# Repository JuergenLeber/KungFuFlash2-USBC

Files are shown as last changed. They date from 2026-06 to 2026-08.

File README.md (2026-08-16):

# Kung Fu Flash 2 USB-C

Cartridge for the Commodore 64 that packs a punch.

This repository is a fork of [KungFuFlash2-USBC](https://github.com/Sgw32/KungFuFlash2-USBC) which is a fork of an earlier version of [KungFuFlash2](https://codeberg.org/KimJorgensen/KungFuFlash2) from Kim Jørgensen that was later moved to Codeberg and is still being updated.

To have the "best of both worlds" (USB-C and updated firmware) this repository merged both of them together and additionally introduces some small fixes to the PCB and the production files.

Kung Fu Flash 2 is the big brother of [Kung Fu Flash](https://codeberg.org/KimJorgensen/KungFuFlash). It has a faster microcontroller with more memory and I/O pins, allowing for additional functionality.

**Currently, this project is considered experimental** and provides the same features as Kung Fu Flash, with these notable exceptions:

* CRT files are loaded into RAM, not flash, making large CRT files startup faster. However, changes to EasyFlash cartridges are lost if power is turned off, unless saved via the menu first
* The cartridge detects if the C64/C128 is reset. This allows the use of an additional reset button on the C64 or the built-in reset button on the C128
* REU emulation has been added

Kung Fu Flash 2 Launcher

Kung Fu Flash 2 can emulate different cartridge types, load PRG files and use D64 disk images.
Just place your desired CRT, PRG or D64 files on a FAT formatted microSD card and use the built-in launcher to execute them.

## Hardware (Rev. 2)

There are three buttons on the cartridge; a reset button, a menu button for starting the launcher, and a special button that is used by the freezer cartridges.

Cartridge Case

A very nice case has been designed by [Bigby](https://www.printables.com/@Bigby) and can be found on [Printables](https://www.printables.com/model/119330-kung-fu-flash-cartridge-case).

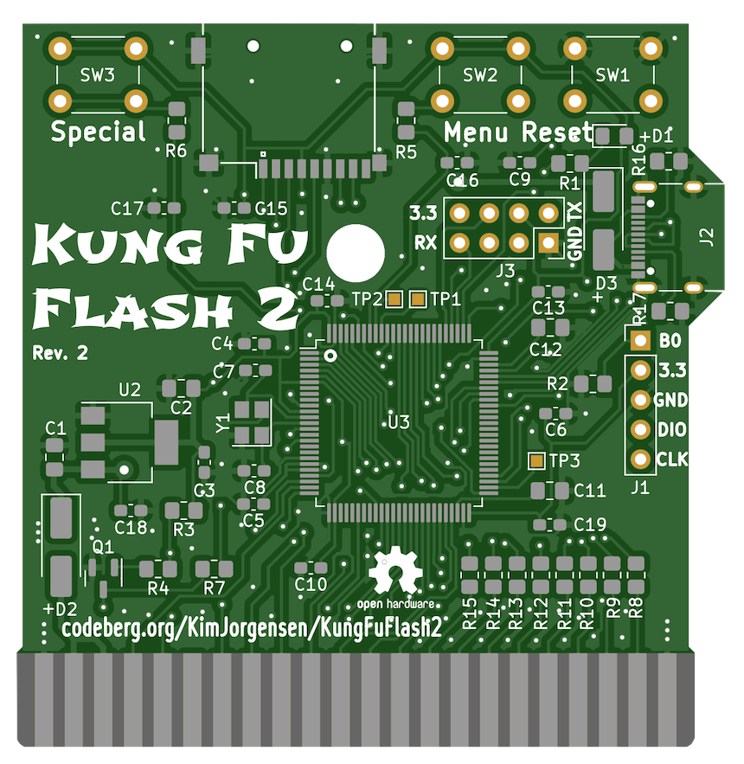
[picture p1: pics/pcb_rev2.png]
Kung Fu Flash 2 PCB


Changes in hardware revision 2 are a USB-C port (including resistors) instead of micro-USB and a different crystal.

As all credits still go to Kim Jørgensen for this great cartridge, the PCB still shows his Codeberg URL.

The gerber files and BOM can be found [here](./hardware/gerber/).

## Supported Cartridges

The following cartridge types are currently supported:

* Generic cartridge (8k, 16k, Ultimax)
* Action Replay v4.x/v5/v6
* KCS Power Cartridge
* Final Cartridge III(+)
* Simons' BASIC
* Fun Play, Power Play
* Super Games
* Ocean type 1
* Epyx Fastload
* C64 Game System, System 3
* WarpSpeed
* Dinamic
* Zaxxon, Super Zaxxon
* Magic Desk, Domark, HES Australia
* Super Snapshot v5
* Comal-80
* Ross
* EasyFlash
* Prophet64
* Freeze Frame
* Freeze Machine
* MACH 5
* Pagefox
* RGCD, Hucky
* Drean
* C128 Generic cartridge (external function ROM)
* WarpSpeed 128

## Supported File Types

The following file types are currently supported:

* Cartridge (CRT)
* C64/C128 generic cartridge (ROM, BIN)
* Disk image (D64, D71, D81)
* Tape image (T64)
* Program (PRG, P00)
* SID tune (SID)
* Firmware update (UPD)
* Text document (TXT, NFO, 1ST)

## SID Playback

SID tunes can be played directly from the launcher. This feature is inherited from the
[KungFuFlash2-USBC](https://github.com/Sgw32/KungFuFlash2-USBC) fork and is not part of the original Kung Fu Flash 2.

Selecting a SID file in the file options menu offers two actions:

* "Play" (RETURN) converts the tune and starts it immediately
* "Convert to PRG" (SHIFT+RETURN) writes a PRG file next to the SID file and returns to the launcher

In both cases the tune is converted to a PRG containing a small BASIC starter and a raster interrupt player,
so the resulting file can also be used on any other C64 setup. As the PRG is written to the microSD card,
the card must not be write protected.

PSID and RSID files of version 1 to 3 are supported, with these limitations:

* Only the first subtune is played; the tune and subtune information from the SID header is ignored
* The player uses a single speed raster interrupt, so multi speed tunes will play at the wrong tempo
* Tunes that load below $0843 cannot be converted, as this area is occupied by the BASIC starter and the player

## REU Emulation

Kung Fu Flash 2 can emulate a 1 Mb REU (RAM Expansion Unit) simultaneously with disk drive emulation.
The REU is enabled in the settings menu (F5) and active when:

* A program is executed using the default option (RETURN)
* A disk image or directory is mounted using "Mount" in the file options menu (SHIFT+RETURN)
* BASIC is started via F6 (C128) or F7 (C64) in the launcher

The REU will not be active when emulating cartridges (CRT files)

## USB Port

The USB port allows programs or disk images to be transferred from/to a PC using the EasyFlash 3 USB protocol.
The USB port is active when:

* The Kung Fu Flash 2 launcher is running
* A program is started using "Load" in the file options menu (SHIFT+RETURN)
* BASIC is started via F7 in the launcher **and** REU emulation is disabled in the settings menu (F5)

Kung Fu Flash 2 shows up as a standard serial port when connected to a PC not requiring any custom drivers to be installed.
This means, however, that the EasyFlash 3 program on the PC side must be modified to support Kung Fu Flash.

The repository of the original Kung Fu Flash contains a modified version of [EasyFlash 3 USB Utilities](https://codeberg.org/KimJorgensen/KungFuFlash/src/branch/master/3rd_party/ef3utils)
and [EasyFlash 3 BBS](https://codeberg.org/KimJorgensen/KungFuFlash/src/branch/master/3rd_party/ef3bbs) which will also work with the Kung Fu Flash 2.

## Firmware Update

Just place the KungFuFlash2_v2.xx.upd file on the SD card and select the file in the launcher to initiate the firmware update.
The newest firmware can be found [here](https://github.com/JuergenLeber/KungFuFlash2-USBC/releases).

For initial firmware installation, [see here](firmware/README.md).

## Limitations

Kung Fu Flash 2 is a so called Software Defined Cartridge where a fast microcontroller emulates cartridge hardware in software.
This makes it extremely flexible, allowing different cartridge types to be supported at a relative low cost.

However, it can be challenging to get the C64 bus timing correct in software and in some places the timing is very close to the limit.
Even though Kung Fu Flash 2 has been tested on different models of the Commodore 64, there is a chance that it doesn't work correctly on your specific model, or requires [phi2 offset adjustment](firmware/README.md#diagnostic).
Use it at your own risk!

Kung Fu Flash 2 will work with the PAL and NTSC version of the Commodore 64 or Commodore 128.

Disk drive emulation is using kernal vectors and will not work with fast loaders or software that uses direct hardware access which a lot of games does.
Currently REL files are not supported and only a subset of the Commodore DOS commands are supported.

## Thanks

Kung Fu Flash 2 was based on or uses other open source projects:

* [Kung Fu Flash](https://codeberg.org/KimJorgensen/KungFuFlash)
* [EasyFlash 3](https://bitbucket.org/skoe/easyflash) by Thomas Giesel
* [Draco Browser](https://csdb.dk/release/?id=89910) by Sascha Bader
* [fatfs-stm32](https://github.com/colosimo/fatfs-stm32) by Aurelio Colosimo
* [FatFs](http://elm-chan.org/fsw/ff/00index_e.html) by ChaN
* [libusb_stm32](https://github.com/dmitrystu/libusb_stm32) by Dmitry Filimonchuk
* [OpenC64Cart](https://github.com/SukkoPera/OpenC64Cart) by Giorgioggì
* [Disk2easyflash](https://csdb.dk/release/?id=150323) by ALeX Kazik

and a few others. Please check the individual files for their license.

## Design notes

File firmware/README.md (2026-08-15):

# Kung Fu Flash 2 Firmware
The initial firmware installation can be done via the SWD interface (J1) using a ST-Link V2 programmer or via the USB port.
The Kung Fu Flash 2 cartridge should not be connected to the Commodore 64 before this process has been completed.

## SWD (Recommended)
Connect the ST-Link V2 programmer to J1 (3.3V, GND, SWDIO, and SWCLK) and connect BOOT0 to 3.3V.

Rename the `KungFuFlash2_v2.xx.upd` file to `KungFuFlash2_v2.xx.bin` and use the STM32CubeProgrammer from ST to program the firmware.

All wires to J1 should be disconnected once the firmware has been successfully installed.

## USB
Add a jumper to short BOOT0 and +3.3V on J1. This will ensure that the board is started in DFU mode.

Use [dfu-util](http://dfu-util.sourceforge.net/) to install the firmware:

`dfu-util -a 0 -s 0x08000000 -D KungFuFlash2_v2.xx.upd`

The jumper should be removed after the firmware has been installed.

## Diagnostic
The diagnostic tool is started by pressing the menu button for 2 seconds (until the LED turns off) and is intended to debug stability problems on some C64 models.
For reference the phi2 clock frequency should be around 985248 Hz for PAL and around 1022727 Hz for NTSC.

The diagnostic tool allows adjusting a phi2 clock offset to address any stability issues.
Some C64 breadbin/longboards may require a small negative phi2 offset and C64C/shortboards may require a small positive offset.

In the diagnostic tool the following buttons on the cartridge can be used:

* `Special`: Decrease offset
* `Menu`: Increase offset
* `Special`, hold for 2 seconds: Save offset and exit
* `Menu`, hold for 2 seconds: Reset offset (without saving)
* `Special` + `Menu`, hold for 2 seconds: Reset and save offset. This combo will also work without starting the diagnostic tool first
* `Reset`: Exit diagnostic tool without saving offset

The phi2 offset is saved to the hidden `.KFF2.cfg` file and is reset if the file is not found on the SD card.

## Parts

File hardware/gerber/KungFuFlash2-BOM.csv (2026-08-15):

# | Reference | Qty | Manf | Manf# | LCSC Part# | Description | Value | Footprint | DNP
1 | C1,C2 | 2 | Samsung Electro-Mechanics | CL21A106KAYNNNG | C318691 |  | 10u | Capacitor_SMD:C_0805_2012Metric_Pad1.18x1.45mm_HandSolder
2 | C3,C4,C5,C6,C9,C10,C13,C14,C15,C16,C17,C18,C19 | 13 | Samsung Electro-Mechanics | CL10B104KB8NNNC | C1591 |  | 100n | Capacitor_SMD:C_0603_1608Metric_Pad1.08x0.95mm_HandSolder
3 | C7,C8 | 2 | Samsung Electro-Mechanics | CL10C200JB81PNC | C346210 |  | 20p | Capacitor_SMD:C_0603_1608Metric_Pad1.08x0.95mm_HandSolder
4 | C11,C12 | 2 | Samsung Electro-Mechanics | CL21B225KBYVPNE | C5362585 |  | 2.2u | Capacitor_SMD:C_0805_2012Metric_Pad1.18x1.45mm_HandSolder
5 | D1 | 1 | Hubei KENTO Elec | KT-0805G | C2297 | LED | Green | LED_SMD:LED_0805_2012Metric_Pad1.15x1.40mm_HandSolder
6 | D2,D3 | 2 | MDD | SS33 | C64998 |  | D_Schottky | Diode_SMD:D_SMA_Handsoldering
7 | J1 | 1 | DNP | DNP | DNP | SWD | DNP | Connector_PinHeader_2.54mm:PinHeader_1x05_P2.54mm_Vertical | DNP
8 | J2 | 1 | Korean Hroparts Elec | TYPE-C-31-M-12 | C165948 | USB-C | USB_C_Receptacle_USB2.0 | Connector_USB:USB_C_Receptacle_XKB_U262-16XN-4BVC11
9 | J3 | 1 | DNP | DNP | DNP | WiFi-Module | DNP | Connector_PinSocket_2.54mm:PinSocket_2x04_P2.54mm_Vertical | DNP
10 | Q1 | 1 | JSMSEMI | BC817 | C916383 |  | BC817-40 | Package_TO_SOT_SMD:SOT-23
11 | R1,R4,R5,R6,R7 | 5 | FH | RS-05K5100FT | C139861 |  | 510R | Resistor_SMD:R_0805_2012Metric_Pad1.20x1.40mm_HandSolder
12 | R2,R3 | 2 | FH | RS-05K1002FT | C115309 |  | 10k | Resistor_SMD:R_0805_2012Metric_Pad1.20x1.40mm_HandSolder
13 | R8,R9,R10,R11,R12,R13,R14,R15 | 8 | FH | RS-05K1000FT | C115424 |  | 100R | Resistor_SMD:R_0805_2012Metric_Pad1.20x1.40mm_HandSolder
14 | R16,R17 | 2 | FH | RS-05K5101FT | C118848 |  | 5.1k | Resistor_SMD:R_0805_2012Metric_Pad1.20x1.40mm_HandSolder
15 | SW1,SW2,SW3 | 3 | SHOU HAN | SH-6X6X5H-CJ | C42416245 | Reset, Menu, Special | Tactile Switch SPST 250gf 5mm PC Pin 6mm x 6mm Through Hole | Button_Switch_THT:SW_PUSH_6mm_H8mm
16 | U2 | 1 | Advanced Monolithic Systems | AMS1117-3.3 | C6186 |  | AMS1117-3.3 | Package_TO_SOT_SMD:SOT-223-3_TabPin2
17 | U3 | 1 | ST | STM32H7B0VBT6 | C730227 |  | STM32H7B0VBTx | Package_QFP:LQFP-100_14x14mm_P0.5mm
18 | XS1 | 1 | SOFNG | TF-15x15 | C111196 |  | uSD_push_push | KungFuFlash2:Conn_uSDcard
19 | Y1 | 1 | YXC Crystal Oscillators | X322525MOB4SI | C9006 |  | 25 MHz | Crystal:Crystal_SMD_3225-4Pin_3.2x2.5mm

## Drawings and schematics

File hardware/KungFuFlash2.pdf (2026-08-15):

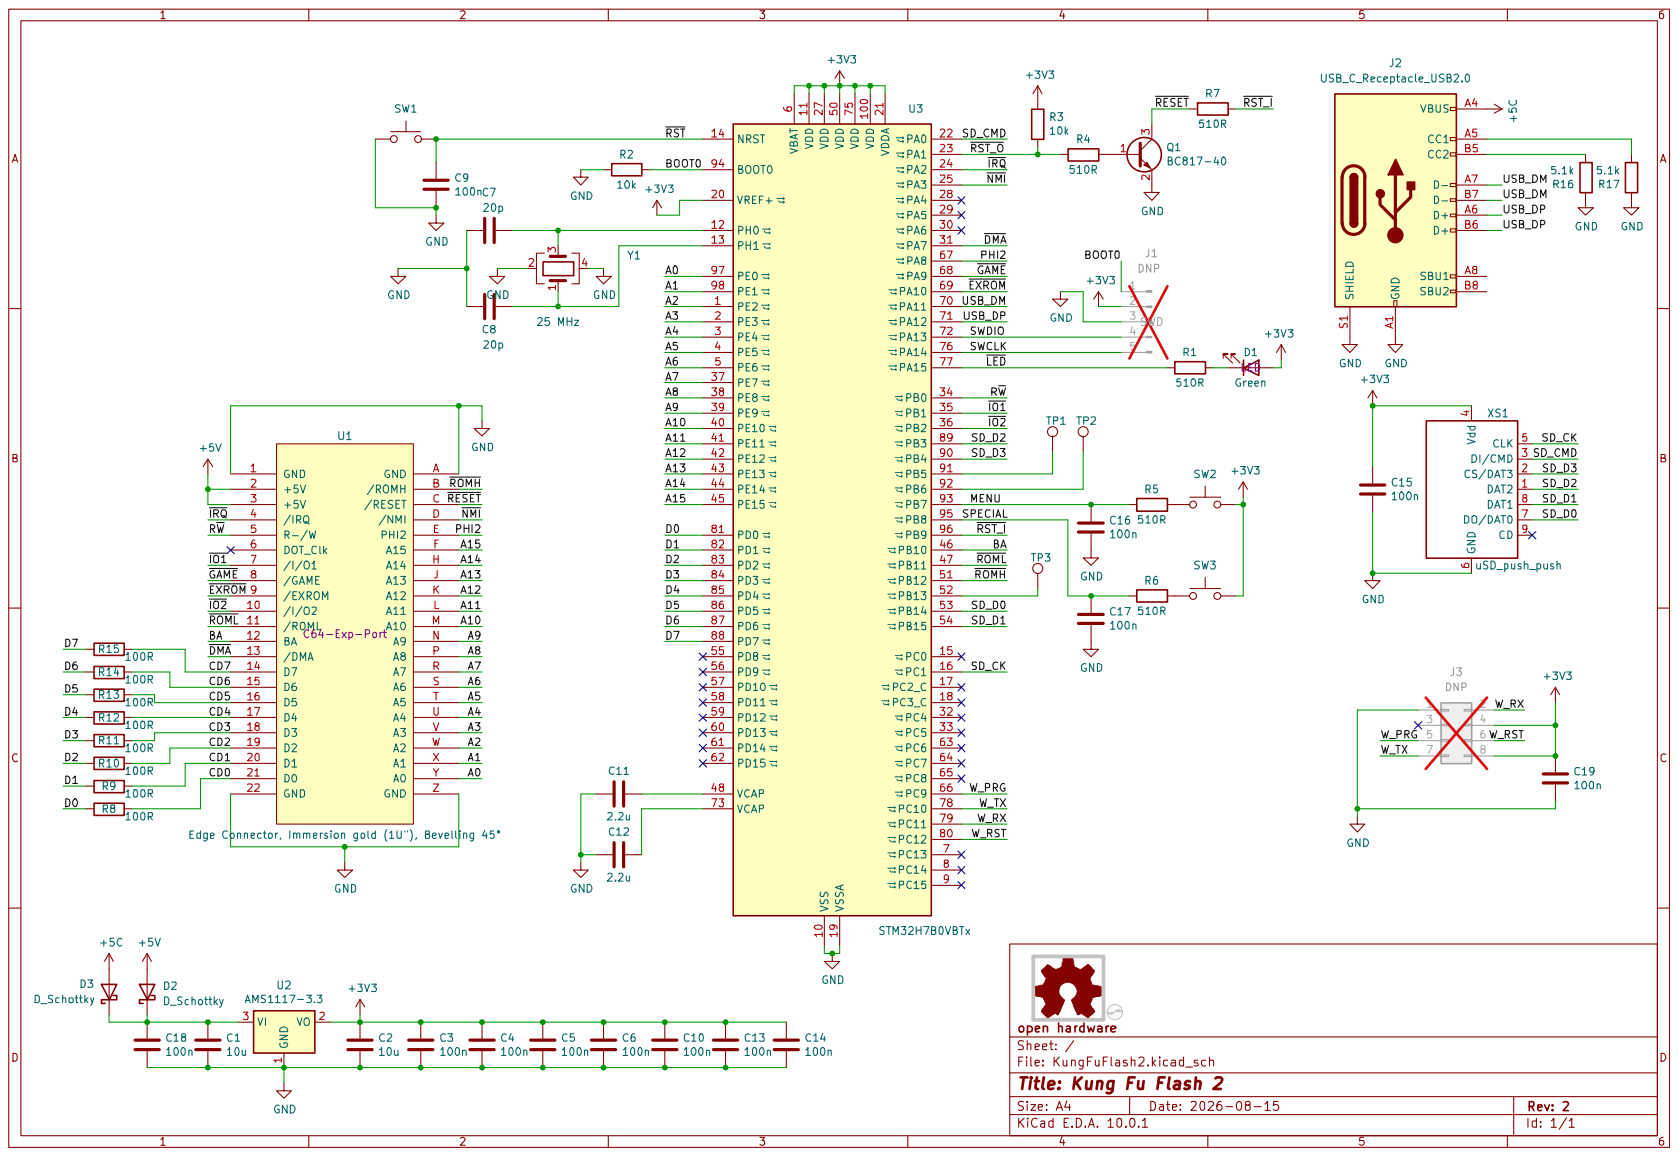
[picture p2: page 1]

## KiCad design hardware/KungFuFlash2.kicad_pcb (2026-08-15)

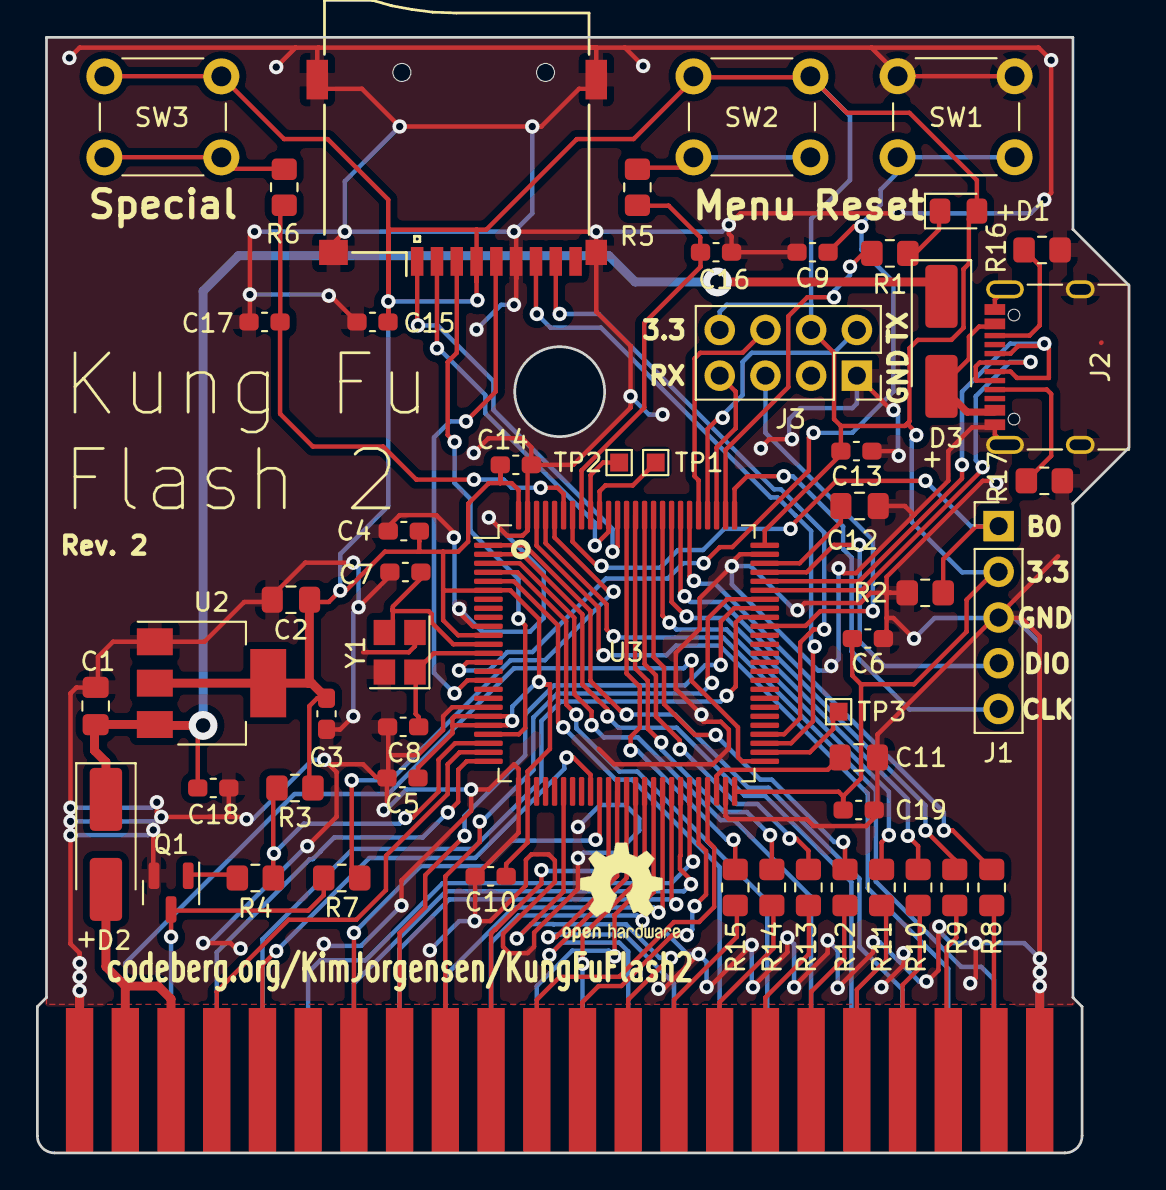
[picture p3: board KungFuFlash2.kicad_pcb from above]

Board: 2 copper layers, 60.6 x 62.0 mm, 54 parts (0 on the bottom side), 84 nets.

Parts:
C1, C2: 10u; C_0805_2012Metric_Pad1.18x1.45mm_HandSolder
C3, C4, C5, C6, C9, C10, C13, C14, C15, C16, C17, C18, C19: 100n; C_0603_1608Metric_Pad1.08x0.95mm_HandSolder
C7, C8: 20p; C_0603_1608Metric_Pad1.08x0.95mm_HandSolder
C11, C12: 2.2u; C_0805_2012Metric_Pad1.18x1.45mm_HandSolder
D1: LED; LED_0805_2012Metric_Pad1.15x1.40mm_HandSolder
D2, D3: D_Schottky; D_SMA_Handsoldering
J1: SWD; PinHeader_1x05_P2.54mm_Vertical
J2: USB_C_Receptacle_USB2.0; USB_C_Receptacle_XKB_U262-16XN-4BVC11
J3: Wifi; PinSocket_2x04_P2.54mm_Vertical
Q1: BC817; SOT-23
R1, R4, R5, R6, R7: 510R; R_0805_2012Metric_Pad1.20x1.40mm_HandSolder
R2, R3: 10k; R_0805_2012Metric_Pad1.20x1.40mm_HandSolder
R8, R9, R10, R11, R12, R13, R14, R15: 100R; R_0805_2012Metric_Pad1.20x1.40mm_HandSolder
R16, R17: 5.1k; R_0805_2012Metric_Pad1.20x1.40mm_HandSolder
SW1: Reset; SW_PUSH_6mm_H8mm
SW2: Menu; SW_PUSH_6mm_H8mm
SW3: Special; SW_PUSH_6mm_H8mm
TP1, TP2, TP3: TestPoint_Pad_1.0x1.0mm
U1: C64-Exp-Port; C64-Cart
U2: AMS1117-3.3; SOT-223-3_TabPin2
U3: STM32H7B0VBTx; LQFP-100_14x14mm_P0.5mm
XS1: uSD_push_push; Conn_uSDcard
Y1: 25 MHz; Crystal_SMD_3225-4Pin_3.2x2.5mm

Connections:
+3V3: C2.1, C3.1, C4.1, C5.1, C6.1, C10.1, C13.1, C14.1, C15.1, C19.1, D1.2 (A), J1.2, J3.4, J3.8, R3.1, SW2.1, SW3.1, U2.2 (VO), U3.6 (VBAT), U3.11 (VDD), U3.20 (VREF+), U3.21 (VDDA), U3.27 (VDD), U3.50 (VDD), U3.75 (VDD), U3.100 (VDD), XS1.4 (Vdd)
+5C: D3.2 (A), J2.A4 (VBUS), J2.A9 (VBUS), J2.B4 (VBUS), J2.B9 (VBUS)
+5V: D2.2 (A), U1.2 (+5V), U1.3 (+5V)
/A0: U1.Y (A0), U3.97 (PE0)
/A1: U1.X (A1), U3.98 (PE1)
/A2: U1.W (A2), U3.1 (PE2)
/A3: U1.V (A3), U3.2 (PE3)
/A4: U1.U (A4), U3.3 (PE4)
/A5: U1.T (A5), U3.4 (PE5)
/A6: U1.S (A6), U3.5 (PE6)
/A7: U1.R (A7), U3.37 (PE7)
/A8: U1.P (A8), U3.38 (PE8)
/A9: U1.N (A9), U3.39 (PE9)
/A10: U1.M (A10), U3.40 (PE10)
/A11: U1.L (A11), U3.41 (PE11)
/A12: U1.K (A12), U3.42 (PE12)
/A13: U1.J (A13), U3.43 (PE13)
/A14: U1.H (A14), U3.44 (PE14)
/A15: U1.F (A15), U3.45 (PE15)
/BA: U1.12 (BA), U3.46 (PB10)
/BOOT0: J1.1, R2.1, U3.94 (BOOT0)
/CD0: R8.1, U1.21 (D0)
/CD1: R9.1, U1.20 (D1)
/CD2: R10.1, U1.19 (D2)
/CD3: R11.1, U1.18 (D3)
/CD4: R12.1, U1.17 (D4)
/CD5: R13.1, U1.16 (D5)
/CD6: R14.1, U1.15 (D6)
/CD7: R15.1, U1.14 (D7)
/D0: R8.2, U3.81 (PD0)
/D1: R9.2, U3.82 (PD1)
/D2: R10.2, U3.83 (PD2)
/D3: R11.2, U3.84 (PD3)
/D4: R12.2, U3.85 (PD4)
/D5: R13.2, U3.86 (PD5)
/D6: R14.2, U3.87 (PD6)
/D7: R15.2, U3.88 (PD7)
/MENU: C16.1, R5.2, U3.93 (PB7)
/PHI2: U1.E (PHI2), U3.67 (PA8)
/R~W: U1.5 (R-/W), U3.34 (PB0)
/SD_CK: U3.16 (PC1), XS1.5 (CLK)
/SD_CMD: U3.22 (PA0), XS1.3 (DI/CMD)
/SD_D0: U3.53 (PB14), XS1.7 (DO/DAT0)
/SD_D1: U3.54 (PB15), XS1.8 (DAT1)
/SD_D2: U3.89 (PB3), XS1.1 (DAT2)
/SD_D3: U3.90 (PB4), XS1.2 (CS/DAT3)
/SPECIAL: C17.1, R6.2, U3.95 (PB8)
/SWCLK: J1.5, U3.76 (PA14)
/SWDIO: J1.4, U3.72 (PA13)
/USB_DM: J2.A7 (D-), J2.B7 (D-), U3.70 (PA11)
/USB_DP: J2.A6 (D+), J2.B6 (D+), U3.71 (PA12)
/W_PRG: J3.5, U3.66 (PC9)
/W_RST: J3.6, U3.80 (PC12)
/W_RX: J3.2, U3.79 (PC11)
/W_TX: J3.7, U3.78 (PC10)
/~DMA: U1.13 (/DMA), U3.31 (PA7)
/~EXROM: U1.9 (/EXROM), U3.69 (PA10)
/~GAME: U1.8 (/GAME), U3.68 (PA9)
/~IO1: U1.7 (/I/O1), U3.35 (PB1)
/~IO2: U1.10 (/I/O2), U3.36 (PB2)
/~IRQ: U1.4 (/IRQ), U3.24 (PA2)
/~LED: R1.1, U3.77 (PA15)
/~NMI: U1.D (/NMI), U3.25 (PA3)
/~RESET: Q1.3 (C), R7.2, U1.C (/RESET)
/~ROMH: U1.B (/ROMH), U3.51 (PB12)
/~ROML: U1.11 (/ROML), U3.47 (PB11)
/~RST_I: R7.1, U3.96 (PB9)
/~RST_O: R3.2, R4.2, U3.23 (PA1)
/~RST: C9.1, SW1.2, U3.14 (NRST)
GND: C1.2, C2.2, C3.2, C4.2, C5.2, C6.2, C7.1, C8.1, C9.2, C10.2, C11.1, C12.2, C13.2, C14.2, C15.2, C16.2, C17.2, C18.2, C19.2, J1.3, J2.A1 (GND), J2.A12 (GND), J2.B1 (GND), J2.B12 (GND), J2.S1 (SHIELD), J3.1, Q1.2 (E), R2.2, R16.1, R17.1, SW1.1, U1.1 (GND), U1.22 (GND), U1.A (GND), U1.Z (GND), U2.1 (GND), U3.10 (VSS), U3.19 (VSSA), U3.26 (VSS), U3.49 (VSS), U3.74 (VSS), U3.99 (VSS), XS1.6 (GND), Y1.2, Y1.4
unnamed: C11.2, U3.48 (VCAP)
unnamed: C12.1, U3.73 (VCAP)
unnamed: D1.1 (K), R1.2
unnamed: C1.1, C18.1, D2.1 (K), D3.1 (K), U2.3 (VI)
unnamed: J2.A5 (CC1), R17.2
unnamed: J2.B5 (CC2), R16.2
unnamed: Q1.1 (B), R4.1
unnamed: R5.1, SW2.2
unnamed: R6.1, SW3.2
unnamed: TP1.1, U3.91 (PB5)
unnamed: TP2.1, U3.92 (PB6)
unnamed: TP3.1, U3.52 (PB13)
unnamed: C7.2, U3.12 (PH0), Y1.3
unnamed: C8.2, U3.13 (PH1), Y1.1

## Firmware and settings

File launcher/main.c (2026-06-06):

/*
 * Copyright (c) 2019-2026 Kim Jørgensen
 *
 * This software is provided 'as-is', without any express or implied
 * warranty.  In no event will the authors be held liable for any damages
 * arising from the use of this software.
 *
 * Permission is granted to anyone to use this software for any purpose,
 * including commercial applications, and to alter it and redistribute it
 * freely, subject to the following restrictions:
 *
 * 1. The origin of this software must not be misrepresented; you must not
 *    claim that you wrote the original software. If you use this software
 *    in a product, an acknowledgment in the product documentation would be
 *    appreciated but is not required.
 * 2. Altered source versions must be plainly marked as such, and must not be
 *    misrepresented as being the original software.
 * 3. This notice may not be removed or altered from any source distribution.
 *
 ******************************************************************************
 * Derived from Draco Browser V1.0C 8 Bit (27.12.2009)
 * Created 2009 by Sascha Bader
 *
 * The code can be used freely as long as you retain
 * a notice describing original source and author.
 *
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
 * Newer versions might be available here: http://www.sascha-bader.de/html/code.html
 */

#include <stdio.h>
#include <string.h>
#include <stdlib.h>
#include <stdbool.h>
#include <ctype.h>
#include <conio.h>
#include <cbm.h>
#include <errno.h>
#include <joystick.h>
#include "screen.h"
#include "dir.h"
#include "base.h"
#include "kff_data.h"
#include "ef3usb_loader.h"
#include "disk.h"
#include "launcher_asm.h"

/* declarations */
static void mainLoopEF3(void);
static void mainLoopKFF(void);
static void textReaderLoop(void);
static uint8_t menuLoop(void);

static void updateScreen(void);
static void help(void);
static bool isSearchChar(uint8_t c);
static uint8_t search(uint8_t c);
static void showDir(void);
static void updateDir(uint8_t last_selected);
static void printDirPage(void);
static void printElement(uint8_t pos);

static const char *kff_receive_text(uint16_t size);
static const char *kff_read_text(void);
static uint8_t kff_sync(void);
static void showFrame(const char *title);
static void showKFFMessage(uint8_t color);
static void showKFFCancel(void);
static void showMessage(const char *text, uint8_t color);

/* definitions */
#define EF3_USB_CMD_LEN 12

static bool isC128 = false;

static char linebuffer[SCREENW+1];
static char inputBuffer[SEARCH_LENGTH+1];
static char searchBuffer[SEARCH_LENGTH+1];
static uint8_t searchLen = 0;
static uint8_t *bigBuffer = NULL;
static uint16_t *pageBuffer = NULL;
static Directory *dir = NULL;

#define KUNG_FU_FLASH_VER "Kung Fu Flash v" ## KFF_VER

// Place program name in the start of the output file
// so it can be read by the firmware
#pragma rodata-name (push, "LOWCODE")
const char programNameVer[FW_NAME_SIZE] = KUNG_FU_FLASH_VER;
#pragma rodata-name (pop)

static const char programBar[] = {"          " KUNG_FU_FLASH_VER "           "};
static const char menuBar[] =    {"          " KUNG_FU_FLASH_VER "  <F1> Help"};

int main(void)
{
    uint8_t i, tmp, tst;
    initScreen(COLOR_BLACK, COLOR_BLACK, TEXTC);

    dir = (Directory *)malloc(sizeof(Directory));
    bigBuffer = (uint8_t *)dir;
    pageBuffer = (uint16_t *)dir;

    if (dir == NULL)
    {
        showMessage("Failed to allocate memory.", ERRORC);
        while (true);
    }

    if (joy_install(&joy_static_stddrv) != JOY_ERR_OK)
    {
        showMessage("Failed to install joystick driver.", ERRORC);
        while (true);
    }

    isC128 = is_c128() != 0;

    if (USB_STATUS == KFF_ID_VALUE) // KFF mode
    {
        mainLoopKFF();
    }
    else    // EF3 mode
    {
        // We can also end up here if there is a hardware problem
        // Test EF3 RAM to make sure we are indeed in EF3 mode
        tst = tmp = EF_RAM_TEST;
        for (i=0; i<=8; i++)
        {
            if (EF_RAM_TEST != tst)
            {
                showMessage("Communication with cartridge failed.", ERRORC);
                cprintf("Check hardware");
                while (true);
            }
            EF_RAM_TEST = tst = 1<<i;
        }
        EF_RAM_TEST = tmp;

        mainLoopEF3();
    }

    free(dir);
    return 0;
}

static void mainLoopEF3(void)
{
    uint8_t i;
    const char *cmd;

    // Get command from Kung Fu Flash cartridge using the EF3 USB protocol
    for (i=0; i<EF3_USB_CMD_LEN; i++)
    {
        cmd = ef3usb_check_cmd();
    }

    while (true)
    {
        if (cmd == NULL)
        {
            showMessage("Communicating with USB...", WARNC);
        }
        else if (strcmp(cmd, "prg") == 0)   // Load PRG
        {
            ef3usb_send_str("load");
            ef3usb_load_and_run();
        }
        else
        {
            showMessage("Received unsupported command.", ERRORC);
            cprintf("Command: %s", cmd);
            ef3usb_send_str("etyp");
        }

        while (!(cmd = ef3usb_check_cmd()));
    }
}

static void mainLoopKFF(void)
{
    const char *text;
    uint8_t cmd, reply, cxy[3];
    uint16_t cmd_wait = 0;

    // Get command from Kung Fu Flash cartridge using the KFF protocol
    while (!(cmd = KFF_GET_COMMAND()) || cmd >= REPLY_OK)
    {
        if (++cmd_wait > 10000)
        {
            cmd_wait = 0;
            showMessage("Waiting for command from cartridge.", ERRORC);
            cprintf("Command: %x", cmd);
        }
    }

    while (true)
    {
        reply = REPLY_OK;
        switch (cmd)
        {
            case CMD_NONE:
                break;

            case CMD_MESSAGE:
                showKFFMessage(TEXTC);
                break;

            case CMD_WARNING:
                showKFFMessage(WARNC);
                waitKey();
                reply = kff_sync();
                break;

            case CMD_FLASH_MESSAGE:
                showKFFMessage(TEXTC);
                textcolor(ERRORC);
                cprintf("PLEASE DO NOT POWER OFF OR RESET");
                reply = kff_sync();
                break;

            case CMD_CANCEL_MESSAGE:
                showKFFCancel();
                reply = kff_sync();
                break;

            case CMD_TEXT:
            case CMD_TEXT_WAIT:
                kff_receive_data(&cxy, sizeof(cxy));
                text = kff_read_text();
                textcolor(cxy[0]);
                cputsxy(cxy[1], cxy[2], text);
                if (cmd == CMD_TEXT_WAIT)
                {
                    reply = kff_sync();
                }
                break;

            case CMD_TEXT_READER:
                textReaderLoop();
                wait_for_reset();
                break;

            case CMD_MENU:
                cmd = menuLoop();
                continue;

            case CMD_WAIT_SYNC:
                clrscr();
                reply = kff_sync();
                break;

            case CMD_MOUNT_DISK:
                disk_mount_and_load();
                break;

            case CMD_WAIT_RESET:
                wait_for_reset();
                break;

            default:
                showMessage("Communication with cartridge failed.", ERRORC);
                cprintf("Unexpected command: %x", cmd);
                break;
        }

        cmd = kff_send_reply(reply);
    }
}

static const char *kff_receive_text(uint16_t size)
{
    kff_receive_data(bigBuffer, size);
    bigBuffer[size] = 0;

    return bigBuffer;
}

static const char *kff_read_text(void)
{
    uint16_t size;
    kff_receive_data(&size, 2);

    return kff_receive_text(size);
}

static void showKFFMessage(uint8_t color)
{
    const char *text = kff_read_text();
    showMessage(text, color);
}

static void showKFFCancel(void)
{
    const char *text = kff_receive_text(DIR_NAME_LENGTH);
    sprintf(linebuffer, "%-39s ", text);
    showFrame(linebuffer);

    textcolor(TEXTC);
    text = kff_read_text();
    cputsxy(0, 3, text);

    textcolor(ERRORC);
    cputsxy(0, 5, "PLEASE DO NOT POWER OFF OR RESET");

    revers(1);
    textcolor(COLOR_PURPLE);
    cputsxy(0, 11, "PRESS A KEY TO CANCEL");
    revers(0);
}

static uint8_t kff_sync(void)
{
    kff_wait_for_sync();

    if (kbhit() || joyhit())
    {
        return REPLY_CANCEL;
    }

    return REPLY_OK;
}

static void showTextPage(uint16_t page)
{
    uint8_t i, chr, last_c = 0;

    clrscr();
    revers(1);
    textcolor(BACKC);
    gotoxy(0, 0);
    KFF_READ_PTR = 0;
    for (i=0; i<DIR_NAME_LENGTH; i++)
    {
        cputc(KFF_DATA);
    }
    cputc(' ');
    cputsxy(0, BOTTOM, programBar);
    revers(0);
    textcolor(TEXTC);
    gotoxy(0, 1);

    KFF_READ_PTR = pageBuffer[page];
    while (true)
    {
        chr = KFF_DATA;
        if (!chr || wherey() >= 24)
        {
            (KFF_READ_PTR)--;
            break;
        }

        if (chr == 0x0a && last_c != 0x0d)  // Handle line endings
        {
            cputs("\r\n");
        }
        else if (chr == 0x09)   // Handle tab
        {
            if ((wherex() % 2) == 0)
            {
                cputs("  ");
            }
            else
            {
                cputc(' ');
            }
        }
        else
        {
            cputc(chr);
        }

        last_c = chr;
    }

    pageBuffer[page + 1] = KFF_READ_PTR;
}

static void textReaderLoop(void)
{
    uint8_t c;
    uint16_t size, page = 0;

    KFF_READ_PTR = DIR_NAME_LENGTH;
    kff_receive_data(&size, 2);
    size++;
    pageBuffer[0] = KFF_READ_PTR;
    showTextPage(0);

    waitRelease();
    while (true)
    {
        c = kbhit() ? cgetc() : getJoy();
        switch (c)
        {
            case CH_ENTER:
            case CH_SHIFT_ENTER:
            case CH_DEL:
            case CH_STOP:
                return;

            case CH_HOME:
            case CH_FIRE_LEFT:
            case CH_FIRE_UP:
                page = 0;
                showTextPage(page);
                break;

            case CH_CURS_DOWN:
            case CH_CURS_RIGHT:
                if (KFF_READ_PTR < size && page < (sizeof(Directory)/2))
                {
                    showTextPage(++page);
                }
                break;

            case CH_CURS_LEFT:
            case CH_CURS_UP:
                if (page)
                {
                    showTextPage(--page);
                }
                break;

            default:
                break;
        }
    }
}

static void updateScreen(void)
{
    clrscr();
    revers(0);
    textcolor(BACKC);
    drawFrame();
    revers(1);
    cputsxy(0, BOTTOM, menuBar);
    revers(0);

    showDir();
}

static uint8_t menuLoop(void)
{
    uint8_t c, last_selected = 0;
    uint8_t data, cmd, reply;

    memset(dir, 0, sizeof(Directory));
    updateScreen();

    cmd = CMD_NONE;
    kff_send_size_data(searchBuffer, searchLen);
    reply = REPLY_DIR;

    while (true)
    {
        if (cmd != CMD_NONE || reply != REPLY_OK)
        {
            cmd = kff_send_reply_progress(reply);
        }

        reply = REPLY_OK;
        switch (cmd)
        {
            case CMD_NONE:
                break;

            case CMD_READ_DIR:
                readDir(dir);
                showDir();
                waitRelease();
                continue;

            case CMD_READ_DIR_PAGE:
                if (!readDirPage(dir))
                {
                    dir->selected = last_selected;
                }

                if (dir->selected >= dir->no_of_elements)
                {
                    dir->selected =
                        dir->no_of_elements ? dir->no_of_elements-1 : 0;
                }

                if (dir->selected < dir->text_elements)
                {
                    dir->selected = dir->text_elements;
                }

                showDir();
                continue;

            default:
                return cmd;
        }

        c = kbhit() ? cgetc() : getJoy();
        switch (c)
        {
            case CH_NONE:
                break;

            // --- start / enter directory
            case CH_ENTER:
            case CH_SHIFT_ENTER:
                if (dir->no_of_elements)
                {
                    data = dir->selected;
                    if (isC128)
                    {
                        data |= SELECT_FLAG_C128;
                    }
                    if (c == CH_SHIFT_ENTER)
                    {
                        data |= SELECT_FLAG_OPTIONS;
                    }

                    KFF_SEND_BYTE(data);
                    reply = REPLY_SELECT;
                }
                break;

            // --- leave directory
            case CH_DEL:
            case CH_FIRE_LEFT:
                if (searchBuffer[0] && *dir->name != ' ')
                {
                    reply = search(c);
                }
                else
                {
                    reply = REPLY_DIR_UP;
                }
                break;

            // --- root directory
            case CH_HOME:
                if (searchBuffer[0] && *dir->name != ' ')
                {
                    reply = search(c);
                }
                else
                {
                    reply = REPLY_DIR_ROOT;
                }
                break;

            case CH_CURS_DOWN:
                if (dir->no_of_elements)
                {
                    last_selected = dir->selected;
                    if ((dir->selected+1) < dir->no_of_elements)
                    {
                        dir->selected++;
                        updateDir(last_selected);
                    }
                    else if (dir->no_of_elements == MAX_ELEMENTS_PAGE)
                    {
                        dir->selected = 0;
                        reply = REPLY_DIR_NEXT_PAGE;
                    }
                }
                break;

            case CH_CURS_UP:
                if (dir->no_of_elements)
                {
                    last_selected = dir->selected;
                    if (dir->selected > dir->text_elements)
                    {
                        dir->selected--;
                        updateDir(last_selected);
                    }
                    else
                    {
                        dir->selected = MAX_ELEMENTS_PAGE-1;
                        reply = REPLY_DIR_PREV_PAGE;
                    }
                }
                break;

            case CH_CURS_RIGHT:
                if (dir->no_of_elements)
                {
                    if (dir->no_of_elements < MAX_ELEMENTS_PAGE)
                    {
                        last_selected = dir->selected;
                        dir->selected = dir->no_of_elements-1;
                        updateDir(last_selected);
                    }
                    else
                    {
                        last_selected = dir->no_of_elements-1;
                        reply = REPLY_DIR_NEXT_PAGE;
                    }
                }
                break;

            case CH_CURS_LEFT:
                if (dir->no_of_elements)
                {
                    last_selected = 0;
                    reply = REPLY_DIR_PREV_PAGE;
                }
                break;

            // --- search
            case CH_INS:
            case CH_FIRE_UP:
                if (*dir->name != ' ')
                {
                    reply = search(c);
                }
                break;

            // --- clear search
            case CH_CLR:
                if (searchBuffer[0] && *dir->name != ' ')
                {
                    reply = search(c);
                }
                break;

            case CH_F1:
                help();
                break;

            case CH_F3:
                reply = REPLY_UTILITIES;
                break;

            case CH_FIRE_DOWN:
                if (searchBuffer[0] && *dir->name != ' ')
                {
                    reply = search(c);
                }
                else
                {
                    reply = REPLY_UTILITIES;
                }
                break;

            case CH_F5:
                reply = REPLY_SETTINGS;
                break;

            case CH_FIRE_RIGHT:
                if (searchBuffer[0] && *dir->name != ' ')
                {
                    reply = search(c);
                }
                else
                {
                    reply = REPLY_SETTINGS;
                }
                break;

            case CH_F6:
                reply = REPLY_BASIC_C128;
                break;

            case CH_F7:
                reply = REPLY_BASIC;
                break;

            case CH_F8:
                reply = REPLY_KILL;
                break;

            case CH_STOP:
                reply = REPLY_RESET;
                break;

            default:
                if (isSearchChar(c) && *dir->name != ' ')
                {
                    reply = search(c);
                }
                break;
        }
    }
}

static bool isSearchChar(uint8_t c)
{
    return (c >= 0x20 && c <= 0x5f) || (c >= 0xc1 && c <= 0xda);
}

static uint8_t search(uint8_t c)
{
    uint8_t cursor_pos, cursor_delay;
    bool changed = false;
    uint8_t i, last_selected = dir->selected;

    dir->selected++;
    printElement(last_selected);
    dir->selected = last_selected;

    textcolor(TEXTC);
    revers(1);
    memcpy(inputBuffer, searchBuffer, searchLen);

    for (i=searchLen; i<SEARCH_LENGTH; i++)
    {
        inputBuffer[i] = ' ';
    }
    inputBuffer[SEARCH_LENGTH] = 0;

    cursor_pos = searchLen < SEARCH_LENGTH ? searchLen : SEARCH_LENGTH;

    while (c != CH_ENTER)
    {
        if (c == CH_HOME)
        {
            cursor_pos = 0;
        }
        else if (c == CH_DEL || c == CH_FIRE_LEFT)
        {
            if (cursor_pos)
            {
                cursor_pos--;
            }
            else
            {
                break;
            }

            for (i=cursor_pos; i<SEARCH_LENGTH-1; i++)
            {
                inputBuffer[i] = inputBuffer[i+1];
            }
            inputBuffer[SEARCH_LENGTH-1] = ' ';
        }
        else if (c == CH_CURS_LEFT)
        {
            if (cursor_pos)
            {
                cursor_pos--;
            }
        }
        else if (c == CH_CLR || c == CH_FIRE_DOWN)
        {
            memset(inputBuffer, ' ', SEARCH_LENGTH);
            break;
        }
        else if (cursor_pos < SEARCH_LENGTH)
        {
            if (c == CH_INS || c == CH_FIRE_UP)
            {
                for (i=SEARCH_LENGTH-1; i>cursor_pos; i--)
                {
                    inputBuffer[i] = inputBuffer[i-1];
                }
                inputBuffer[cursor_pos] = ' ';
            }
            else if (c == CH_CURS_RIGHT)
            {
                cursor_pos++;
            }
            else if (c == CH_CURS_UP)
            {
                c = inputBuffer[cursor_pos] + 1;
                if (c < 0x2a)   // '*'
                {
                    c = 'a';
                }
                else if (c < 0x30)  // '0'
                {
                    c = '0';
                }
                else if (c > 0x39 && c < 0x41)  // '9' - 'a'
                {
                    c = ' ';
                }
                else if (c > 0x5a)  // 'z'
                {
                    c = '*';
                }

                inputBuffer[cursor_pos] = c;
            }
            else if (c == CH_CURS_DOWN)
            {
                c = inputBuffer[cursor_pos] - 1;
                if (c < 0x20)   // ' '
                {
                    c = '9';
                }
                else if (c < 0x2a)  // '*'
                {
                    c = 'z';
                }
                else if (c < 0x30)   // '0'
                {
                    c = '*';
                }
                else if (c > 0x39 && c < 0x41)  // '9' - 'a'
                {
                    c = ' ';
                }
                else if (c > 0x5a)  // 'z'
                {
                    c = ' ';
                }

                inputBuffer[cursor_pos] = c;
            }
            else if (isSearchChar(c))
            {
                inputBuffer[cursor_pos++] = c;
            }
        }

        sprintf(linebuffer, " Search: %s ", inputBuffer);
        cputsxy(0, 0, linebuffer);

        cursor_delay = 0;
        while (true)
        {
            if (cursor_delay == 0)
            {
                SCREEN_RAM[9 + cursor_pos] ^= 0x80;
                cursor_delay = 120;
            }
            cursor_delay--;

            if (kbhit())
            {
                c = cgetc();
                if (c != CH_CURS_UP && c != CH_CURS_DOWN)
                {
                    break;
                }
            }

            c = getJoy();
            if (c)
            {
                if (c == CH_FIRE_RIGHT)
                {
                    c = ' ';
                }
                break;
            }
        }
        revers(1);
    }

    for (i=SEARCH_LENGTH; i>0; i--) // remove trailing space
    {
        if (inputBuffer[i-1] == ' ')
        {
            inputBuffer[i-1] = 0;
        }
        else
        {
            break;
        }
    }
    searchLen = i;

    for (i=0; i<=searchLen; i++)
    {
        if (searchBuffer[i] != inputBuffer[i])
        {
            changed = true;
            searchBuffer[i] = inputBuffer[i];
        }
    }

    if (!changed)
    {
        showDir();
        waitRelease();
        return REPLY_OK;
    }

    kff_send_size_data(searchBuffer, searchLen);
    return REPLY_DIR;
}
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

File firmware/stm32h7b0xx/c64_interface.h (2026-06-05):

/*
 * Copyright (c) 2019-2026 Kim Jørgensen
 *
 * This software is provided 'as-is', without any express or implied
 * warranty.  In no event will the authors be held liable for any damages
 * arising from the use of this software.
 *
 * Permission is granted to anyone to use this software for any purpose,
 * including commercial applications, and to alter it and redistribute it
 * freely, subject to the following restrictions:
 *
 * 1. The origin of this software must not be misrepresented; you must not
 *    claim that you wrote the original software. If you use this software
 *    in a product, an acknowledgment in the product documentation would be
 *    appreciated but is not required.
 * 2. Altered source versions must be plainly marked as such, and must not be
 *    misrepresented as being the original software.
 * 3. This notice may not be removed or altered from any source distribution.
 */

/******************************************************************************
* C64 address bus on PE0-PE15
* Returned as 32 bit value for performance
******************************************************************************/
#define C64_ADDR_READ() (GPIOE->IDR)

#define C64_ADDR_WRITE(addr)                    \
    /* Make PE0-PE15 outout */                  \
    GPIOE->MODER = 0x55555555;                  \
    GPIOE->ODR = addr

#define C64_ADDR_INPUT()                        \
    /* Make PE0-PE15 input */                   \
    GPIOE->MODER = 0

/******************************************************************************
* C64 data bus on PD0-PD7
* Returned as 32 bit value for performance
******************************************************************************/
#define C64_DATA_READ() (GPIOD->IDR)

#define C64_DATA_WRITE(data)                    \
    /* Make PD0-PD7 outout */                   \
    *((volatile u16 *)&GPIOD->MODER) = 0x5555;  \
    *((volatile u8 *)&GPIOD->ODR) = (data);     \
    COMPILER_BARRIER()

#define C64_DATA_INPUT()                        \
    /* Make PD0-PD7 input */                    \
    *((volatile u16 *)&GPIOD->MODER) = 0x0000;  \
    COMPILER_BARRIER()

/******************************************************************************
* C64 control bus on PB0-PB2 and PB10-PB12, and C64 reset detect on PB9
* Menu button & special button on PB7 & PB8
* Returned as 32 bit value for performance
******************************************************************************/
#define C64_WRITE_HIGH  GPIO_BSRR_BS0
#define C64_WRITE_LOW   GPIO_BSRR_BR0

#define C64_WRITE       GPIO_IDR_ID0    // R/W on PB0
#define C64_IO1         GPIO_IDR_ID1    // IO1 on PB1
#define C64_IO2         GPIO_IDR_ID2    // IO1 on PB2

#define MENU_BTN        GPIO_IDR_ID7    // Menu button on PB7
#define SPECIAL_BTN     GPIO_IDR_ID8    // Special button on PB8
#define C64_RESET       GPIO_IDR_ID9    // Reset detect on PB9

#define C64_BA          GPIO_IDR_ID10   // BA on PB10
#define C64_ROML        GPIO_IDR_ID11   // ROML on PB11
#define C64_ROMH        GPIO_IDR_ID12   // ROMH on PB12

#define C64_CONTROL_READ()          (GPIOB->IDR)
#define C64_CONTROL_WRITE(state)    GPIOB->BSRR = (state)

static void c64_reset_detect_enable(void)
{
    // Enable PB9 interrupt
    EXTI->PR1 = EXTI_PR1_PR9;
    EXTI->IMR1 |= EXTI_IMR1_IM9;
}

static inline void c64_reset_detect_disable(void)
{
    // Disable PB9 interrupt
    EXTI->IMR1 &= ~EXTI_IMR1_IM9;
}

/******************************************************************************
* C64 IRQ and NMI on PA2 & PA3
* C64 DMA, GAME, and EXROM on PA7 & PA9-PA10
* Status LED on PA15
******************************************************************************/
#define C64_IRQ_HIGH        GPIO_BSRR_BS2
#define C64_IRQ_LOW         GPIO_BSRR_BR2
#define C64_NMI_HIGH        GPIO_BSRR_BS3
#define C64_NMI_LOW         GPIO_BSRR_BR3
#define C64_IRQ_NMI_HIGH    (C64_IRQ_HIGH|C64_NMI_HIGH)
#define C64_IRQ_NMI_LOW     (C64_IRQ_LOW|C64_NMI_LOW)

#define C64_DMA_HIGH        GPIO_BSRR_BS7
#define C64_DMA_LOW         GPIO_BSRR_BR7

#define C64_GAME_HIGH       GPIO_BSRR_BS9
#define C64_GAME_LOW        GPIO_BSRR_BR9
#define C64_EXROM_HIGH      GPIO_BSRR_BS10
#define C64_EXROM_LOW       GPIO_BSRR_BR10

#define STATUS_LED_ON       GPIO_BSRR_BR15
#define STATUS_LED_OFF      GPIO_BSRR_BS15

#define C64_CRT_CONTROL(state) GPIOA->BSRR = (state)

static inline void led_off(void)
{
    C64_CRT_CONTROL(STATUS_LED_OFF);
}

static inline void led_on(void)
{
    C64_CRT_CONTROL(STATUS_LED_ON);
}

static void led_toggle(void)
{
    u32 status_led = STATUS_LED_OFF;
    if (GPIOA->ODR & GPIO_ODR_OD15)
    {
        status_led = STATUS_LED_ON;
    }

    C64_CRT_CONTROL(status_led);
}

/******************************************************************************
* C64 clock input on PA8 (timer 1)
******************************************************************************/

// C64_BUS_HANDLER timing
#define NTSC_PHI2_HIGH      154
#define NTSC_PHI2_INT       (NTSC_PHI2_HIGH - 58)
#define NTSC_PHI2_LOW       236

#define PAL_PHI2_HIGH       164
#define PAL_PHI2_INT        (PAL_PHI2_HIGH - 59)
#define PAL_PHI2_LOW        249

// C64_DMA_BUS_HANDLER timing
#define PHI2_DMA_INT_OFFSET 65
#define PHI2_DMA_OFFSET     76

#define NTSC_PHI2_INT_DMA   (NTSC_PHI2_INT - PHI2_DMA_INT_OFFSET)
#define NTSC_PHI2_HIGH_DMA  (NTSC_PHI2_HIGH - PHI2_DMA_OFFSET)

#define PAL_PHI2_INT_DMA    (PAL_PHI2_INT - PHI2_DMA_INT_OFFSET)
#define PAL_PHI2_HIGH_DMA   (PAL_PHI2_HIGH - PHI2_DMA_OFFSET)

#define NOP()                           \
 /* This dummy read takes 1 cycle */    \
 (void)DWT->CYCCNT

#define WAIT_UNTIL(until)   \
    while (DWT->CYCCNT < until)

#define C64_BUS_HANDLER(name)                                                   \
    C64_BUS_HANDLER_(name##_handler, name##_read_handler, name##_write_handler)

#define C64_BUS_HANDLER_READ(name, read_handler)                                \
    C64_BUS_HANDLER_(name##_handler, read_handler, name##_write_handler)
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

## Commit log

2025-12-18 Move to Codeberg
    [KungFuFlash2.kicad_pcb]
2026-04-11 Reset to menu via USB (from KFF v1.54)
    [usb.c]
2026-08-15 chore: ignore KiCad backup files in .gitignore
2026-08-15 fix: rename J4 to J2, move label for R17, update URL of repo
    [KungFuFlash2.kicad_pcb]
2026-08-15 fix: update schematic revision and export new PDF
    [KungFuFlash2.kicad_sch]
2026-08-15 chore: ignore KiCad .history and add to .gitignore
2026-08-15 fix: update PCB revision
    [KungFuFlash2.kicad_pcb]
2026-08-15 feat: update symbol table fields with BOM information for production
    [KungFuFlash2.kicad_pcb, KungFuFlash2.kicad_sch]
2026-08-15 feat: add updated production files (gerbers, BOM, centroid), remove old ones
    [BOM-KungFuFlash2.csv, KungFuFlash2-BOM.csv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]
